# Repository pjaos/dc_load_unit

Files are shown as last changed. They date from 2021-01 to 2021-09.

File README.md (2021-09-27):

# DC Load Unit
I started this project with some basic requirements.

- Voltages up to 100 V
- Provide loads of up to 200W
- WiFi interface
- Web based interface providing stats and plotting capabilities

## Design
I used an ESP32 processor in the design as the main processor using  [Mongoose OS](https://mongoose-os.com/) After some investigations and prototyping I eventually settled on the schematic shown below.

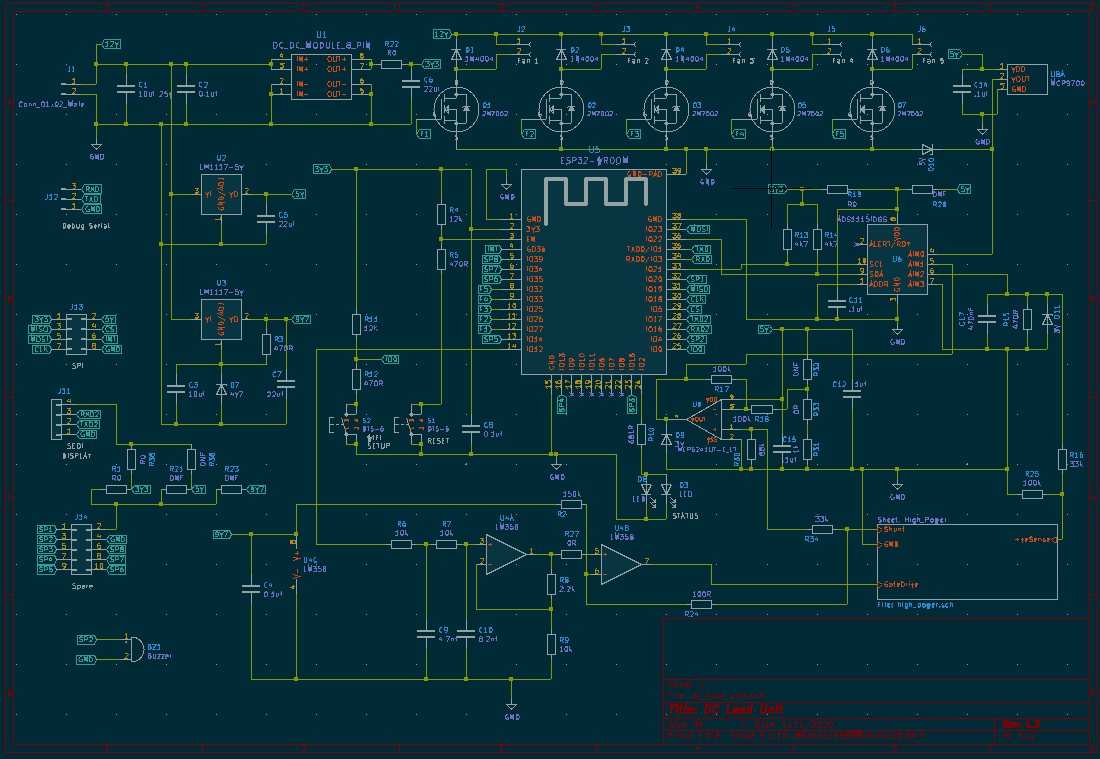
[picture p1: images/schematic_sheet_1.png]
Sheet 1

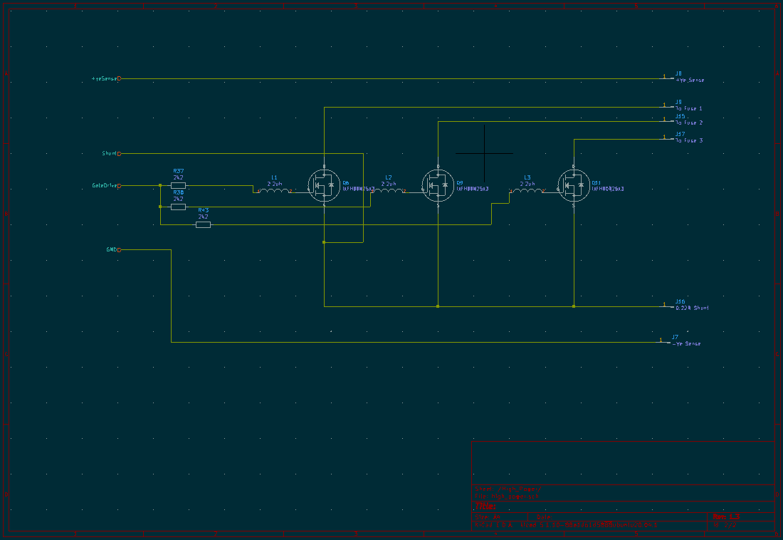
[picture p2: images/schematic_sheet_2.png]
Sheet 1


From the schematic a PCB was created as shown below

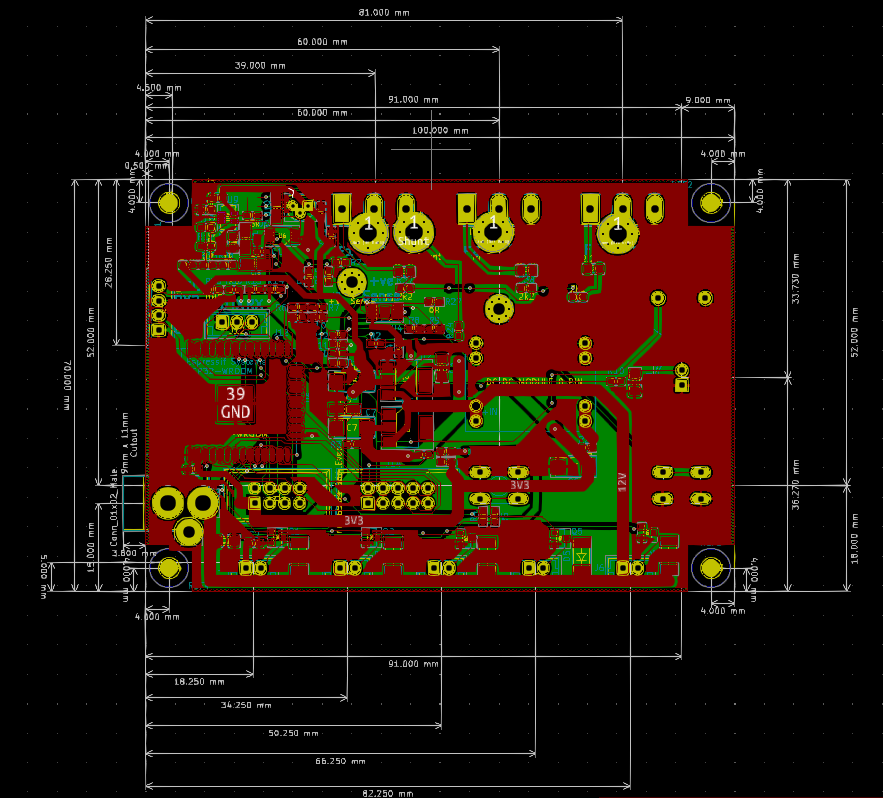
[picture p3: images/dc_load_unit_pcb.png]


Tests on completion of the load unit showed it was capable of providing a load of 280W.

- Images of the completed unit.

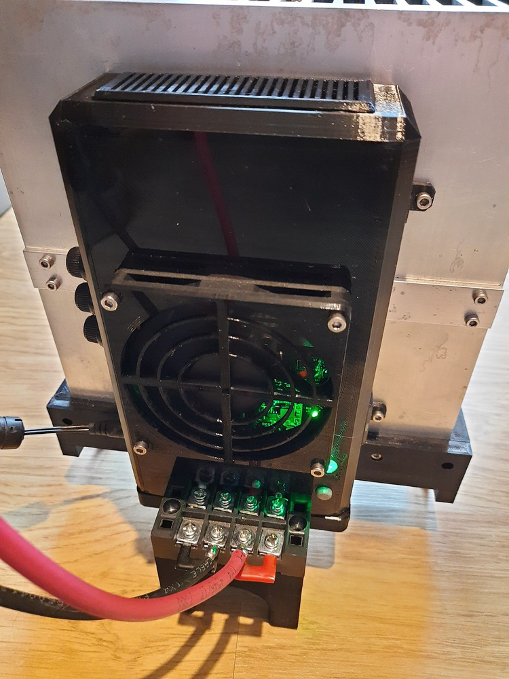
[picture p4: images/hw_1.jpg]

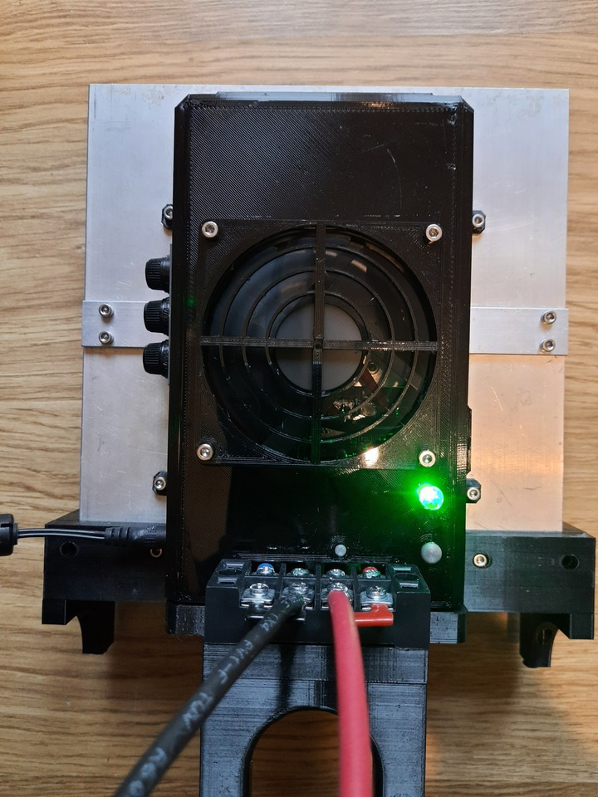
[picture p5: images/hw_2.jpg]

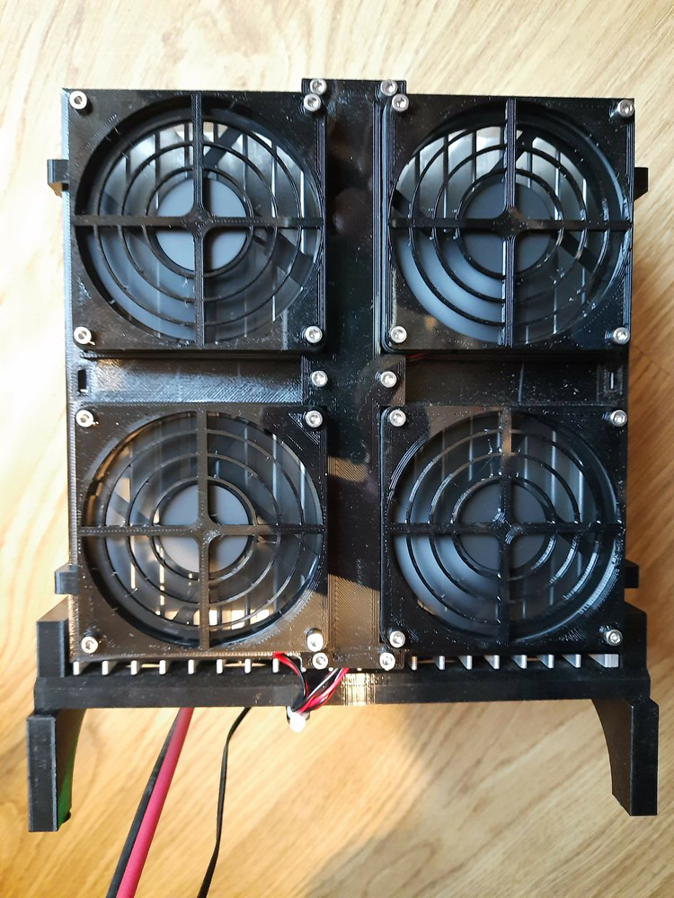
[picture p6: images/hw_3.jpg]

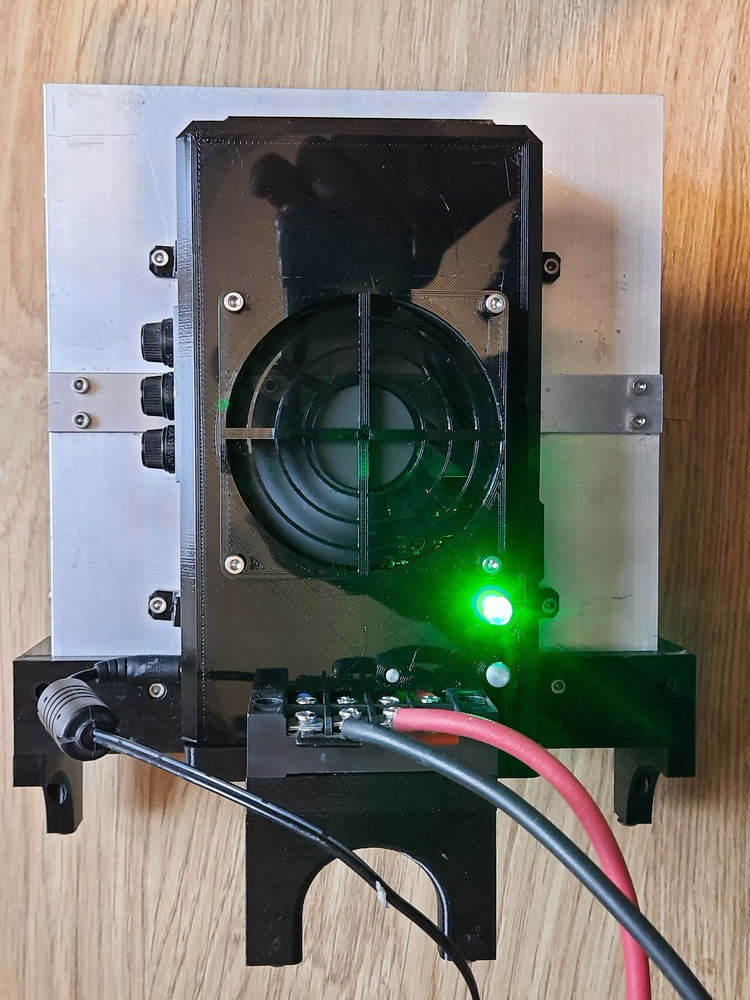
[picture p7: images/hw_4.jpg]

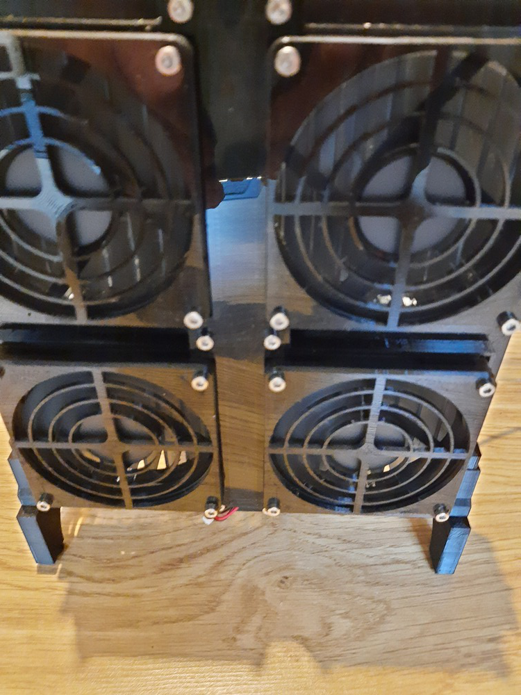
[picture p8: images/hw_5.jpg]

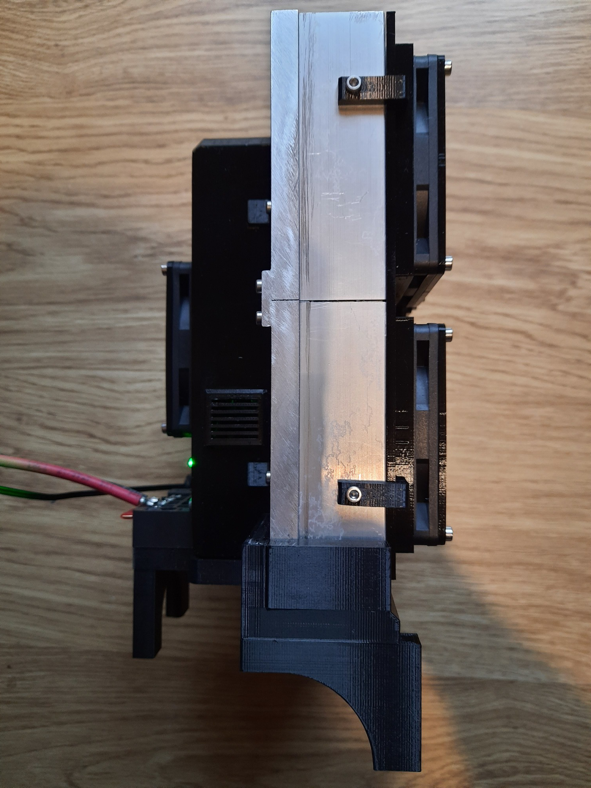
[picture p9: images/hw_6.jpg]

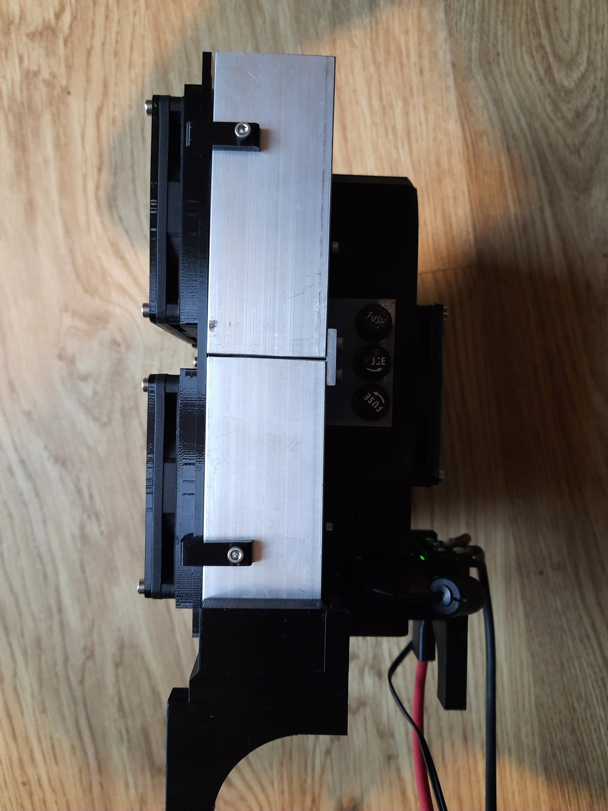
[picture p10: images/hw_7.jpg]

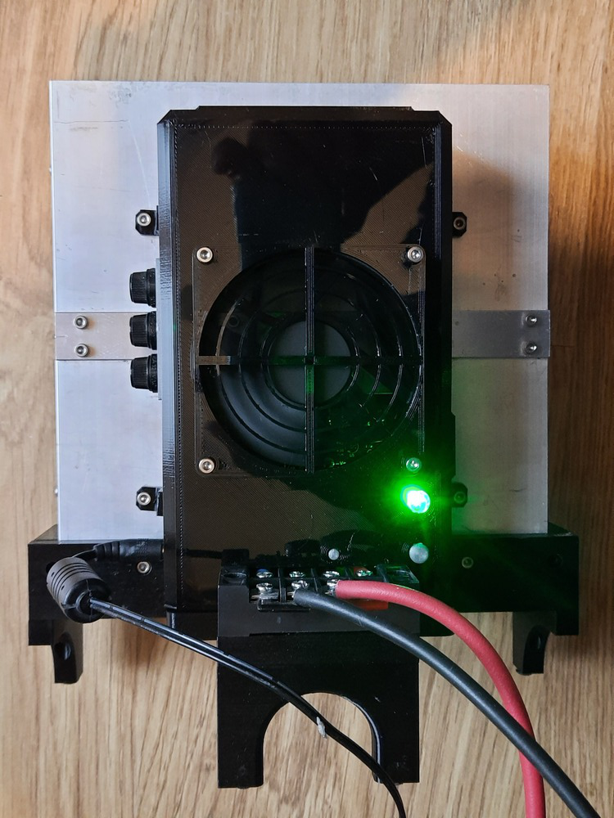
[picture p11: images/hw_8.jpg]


The green LED on the unit indicates that it is connected to the WiFi.

## Web interface
The web interface uses a tabbed pane structure as shown below.

### Main interface
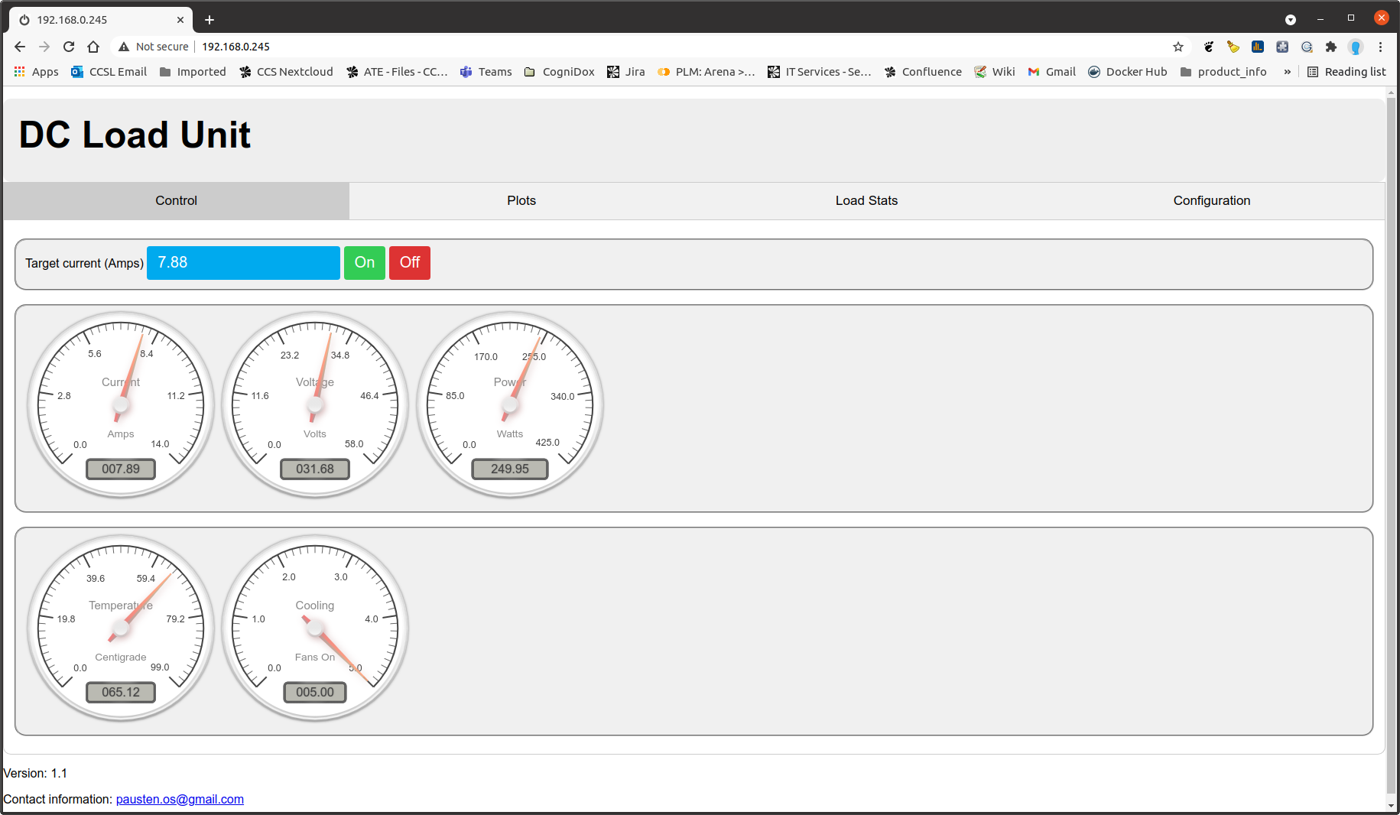
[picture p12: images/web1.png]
Initial Web page


- Plots
The plots tab displays the amps, volts, Watts and Temperature against time as show below.
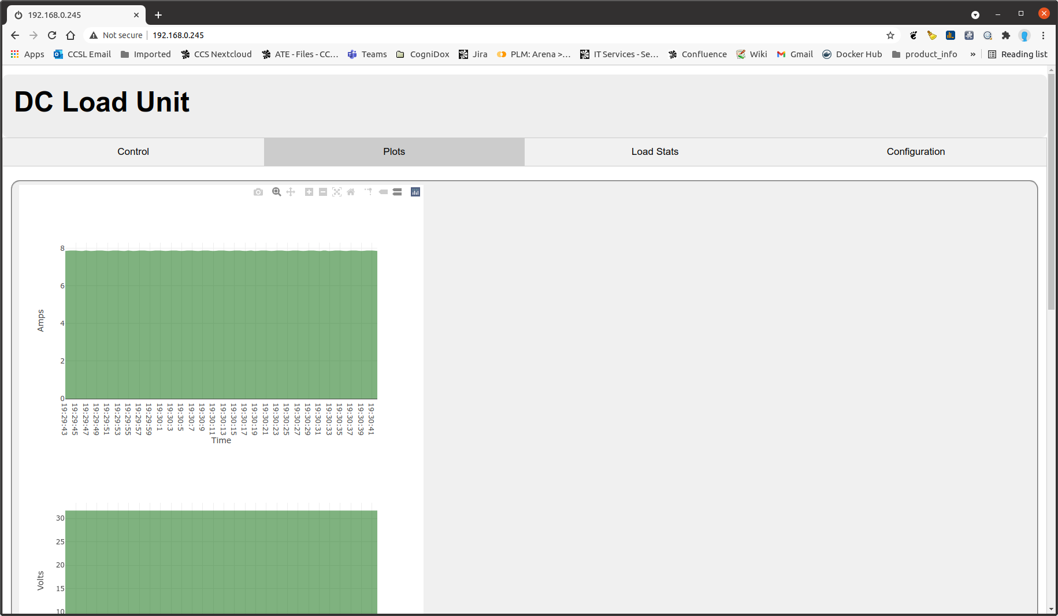
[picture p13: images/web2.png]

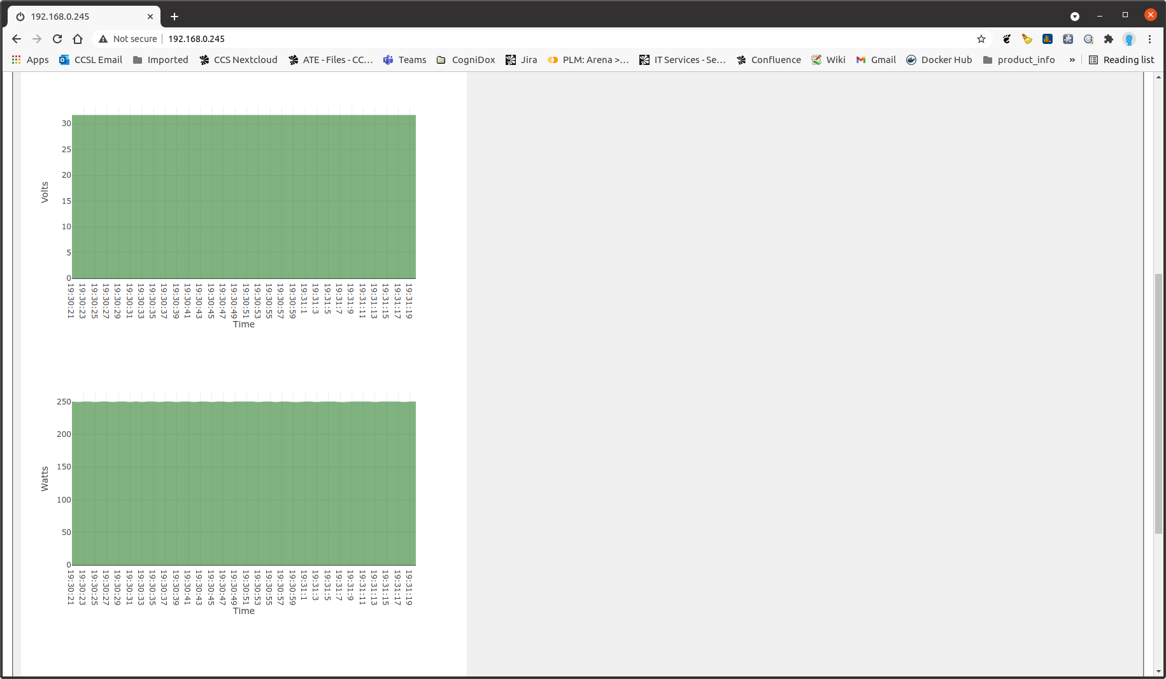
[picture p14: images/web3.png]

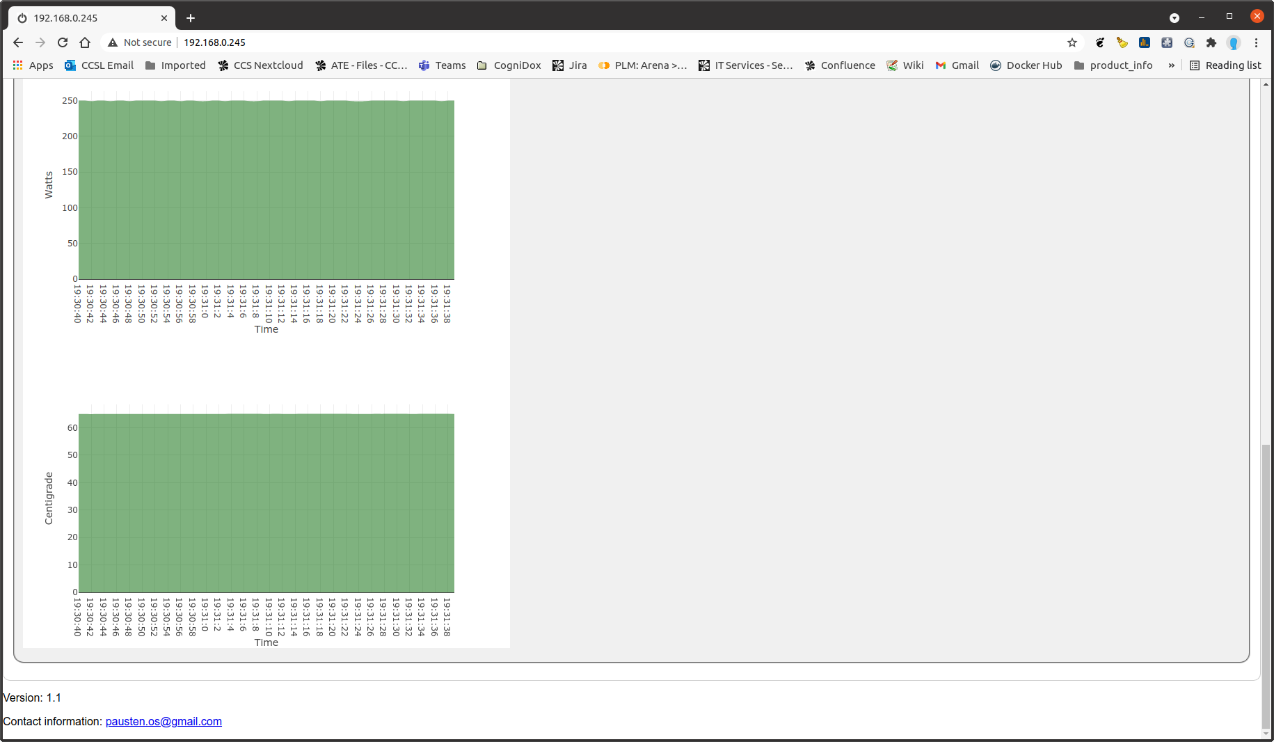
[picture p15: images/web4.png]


- Load stats
The load stats page records the load in amp hours and watt hours. The top two dials show the current accumulating values and the bottom two dials show the previous values. The previous values are useful for showing the total capacity of a battery tested.

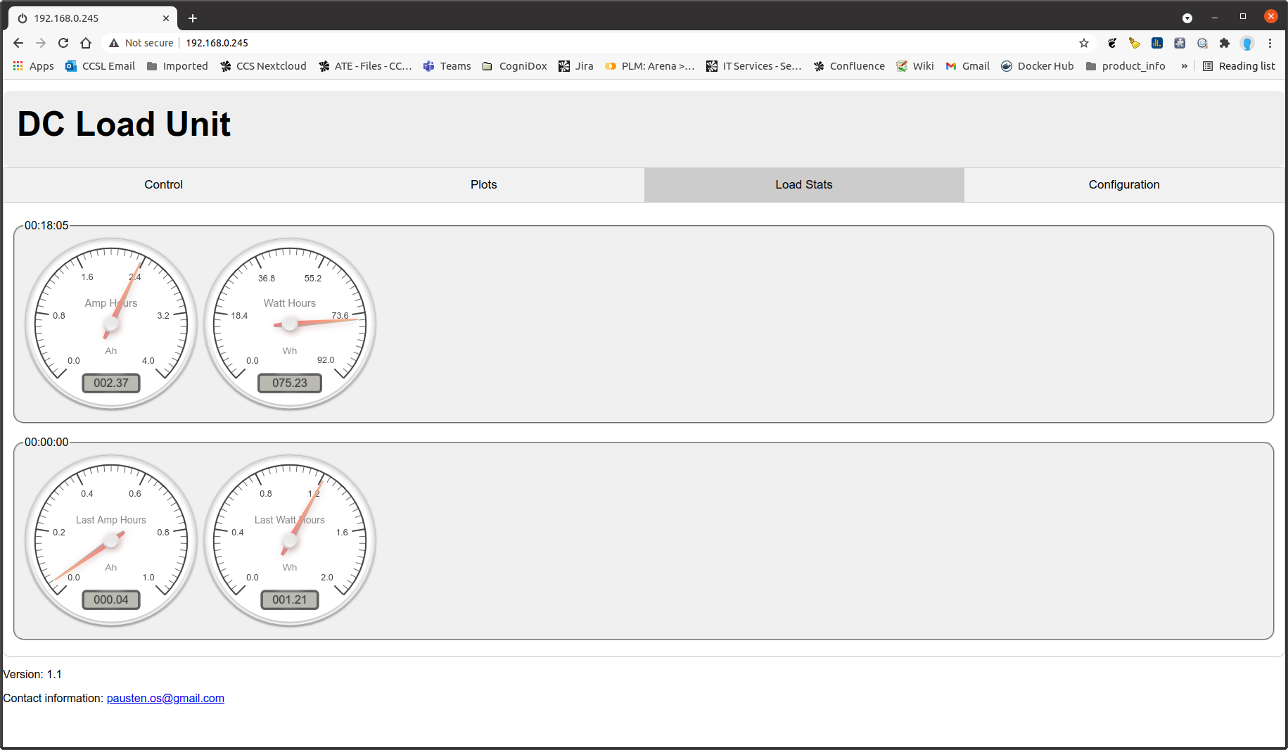
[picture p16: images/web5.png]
Load Stats


- Configuration
The configuration page details the settings for the unit as detailed below.

- Device name:

 The name that appears at the top of the web page and also in the [Yview](https://github.com/pjaos/yview) as the device provides integration into the YView network.

- Group name:

  The YView group name. See [Yview](https://github.com/pjaos/yview) for more details.

- Enable syslog

  If enabled then syslog data is sent to the source of the AYT messages (YView gateway).

- Max Plot values

  Defines the max number of points on the displayed plots.

- Max power

  This defines the maximum power the load will handle. This is limited to 280 Watts. When testing it can be useful to set this value to the max load that the device under test will deliver in order not to inadvertently overload the device under test.

- Load Shutdown Voltage

  When testing battery packs the voltage will drop as the battery looses charge. This setting allows the user to ensure the battery voltage does not drop to far possibly damaging the battery.

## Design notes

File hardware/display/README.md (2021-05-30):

# Display board
This was a side project of an LCD display board that could be used with the
dc load unit to control it. However the web interface is my preferred
GUI interface and therefore I did not develop this board any further.

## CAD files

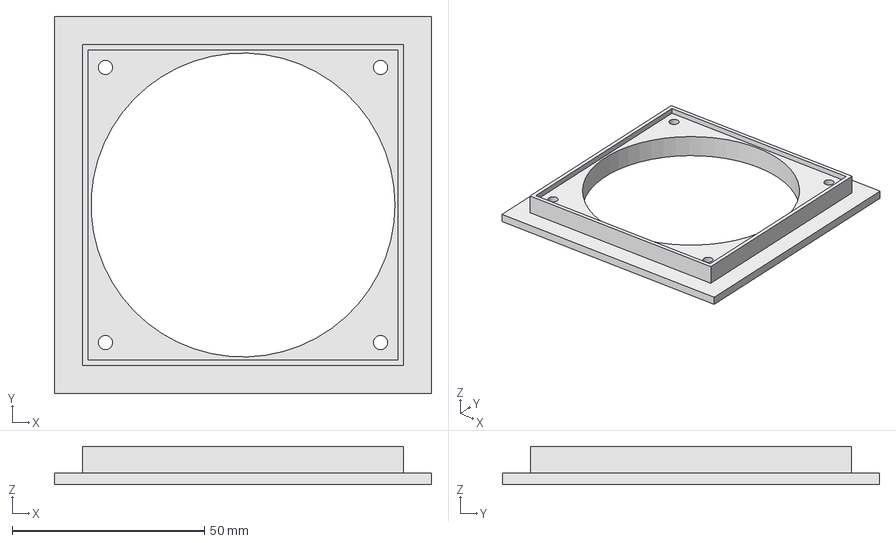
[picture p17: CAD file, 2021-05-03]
case/fan_test_part_1.FCStd
98.0 x 98.0 x 10.0 mm

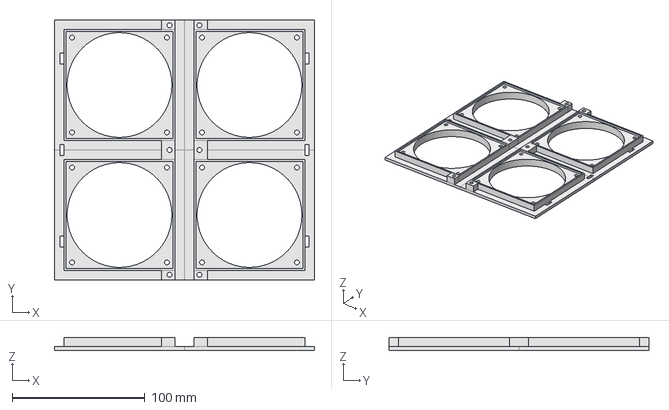
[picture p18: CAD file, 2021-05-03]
case/fan_holder_mk2.FCStd
196.0 x 196.0 x 10.0 mm

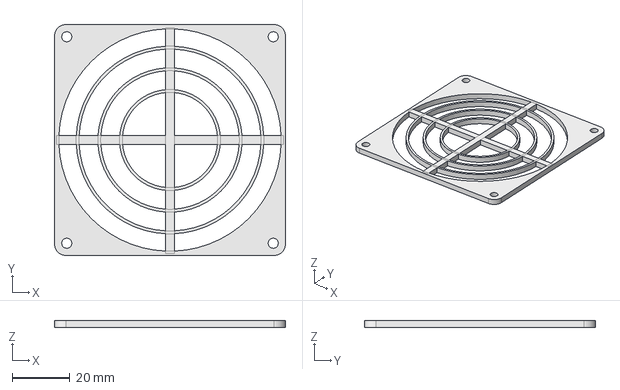
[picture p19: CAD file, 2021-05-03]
case/fan_cover_mk1.FCStd
80.0 x 80.0 x 2.50 mm

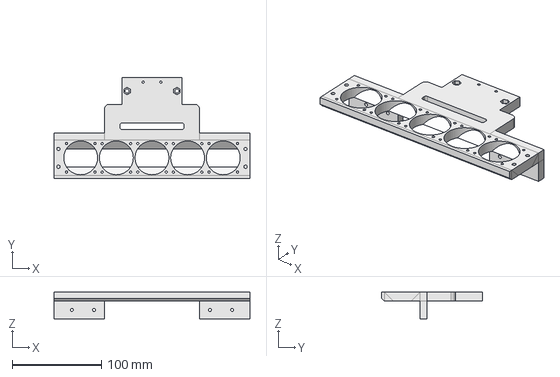
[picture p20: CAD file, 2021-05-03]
case/base_MK2.FCStd
220.0 x 113.0 x 30.0 mm

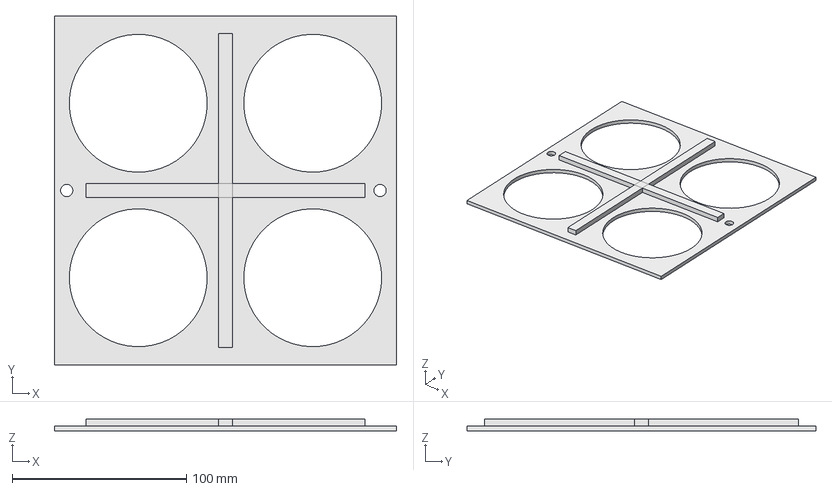
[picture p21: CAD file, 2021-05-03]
case/fan_holder_mk1.FCStd
196.0 x 200.0 x 7.00 mm

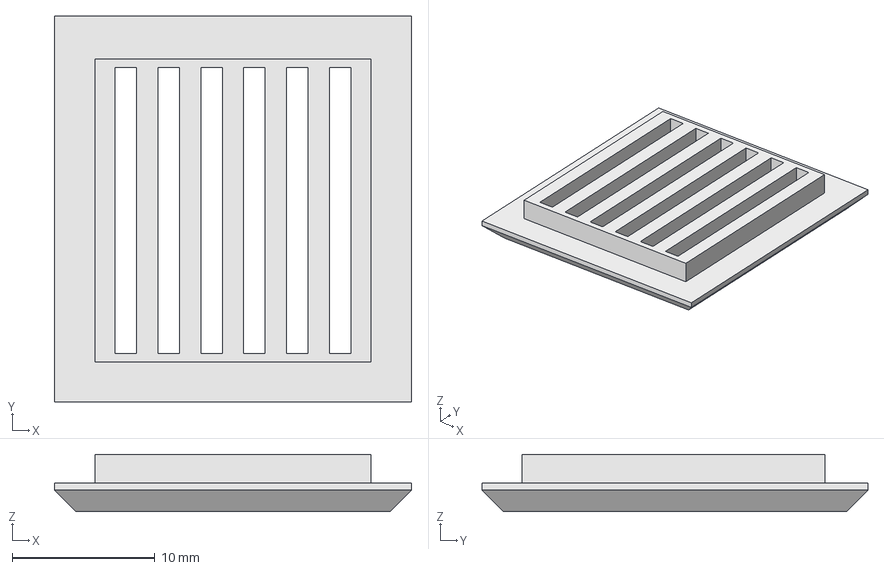
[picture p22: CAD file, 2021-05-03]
case/side_grill.FCStd
25.0 x 27.0 x 4.00 mm

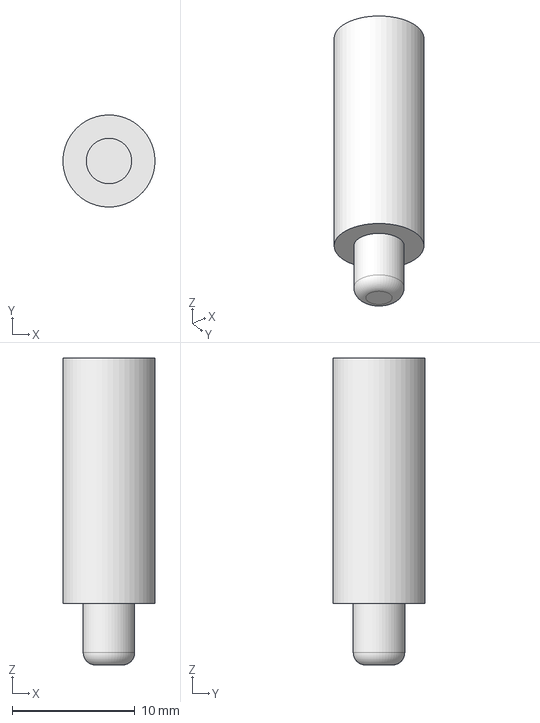
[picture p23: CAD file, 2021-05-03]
case/reset_button.FCStd
7.49 x 7.50 x 25.0 mm

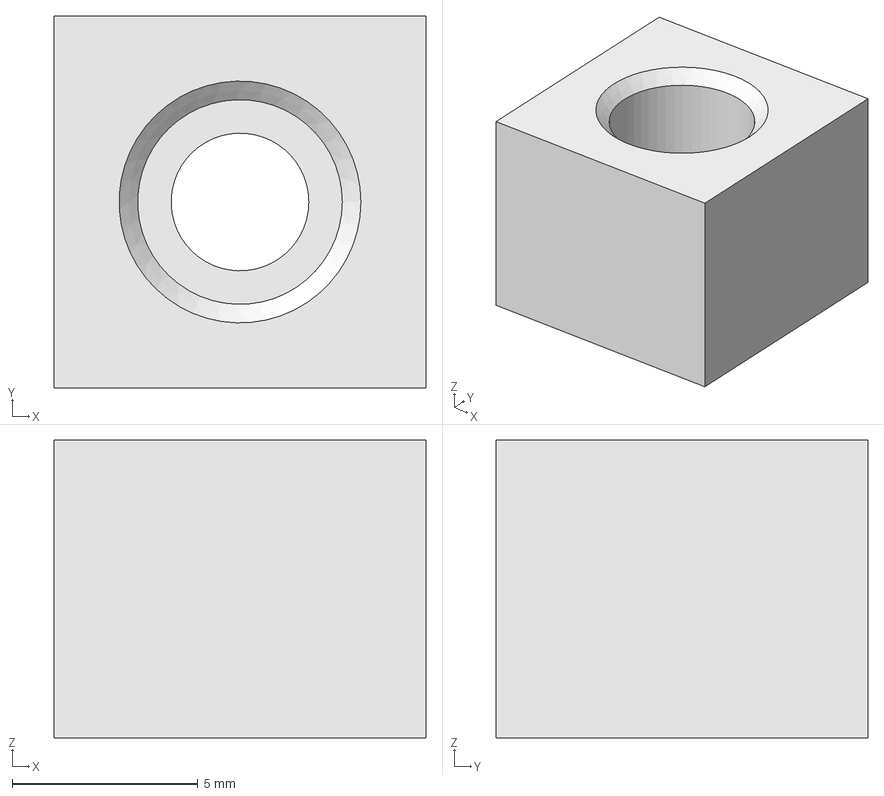
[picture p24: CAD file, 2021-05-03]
case/insert_test_part_mk1.FCStd
10.0 x 10.0 x 8.00 mm

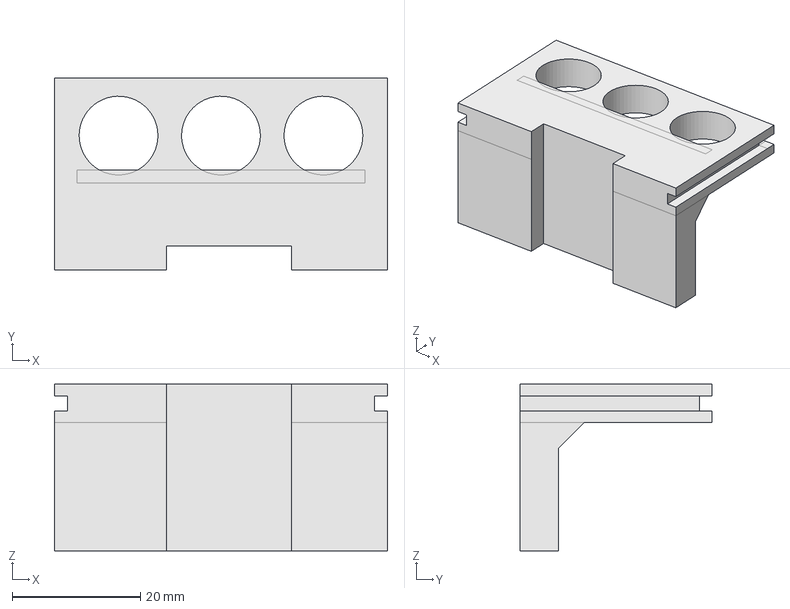
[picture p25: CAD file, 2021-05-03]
case/fuse_holder_bracket.FCStd
52.0 x 30.0 x 26.0 mm

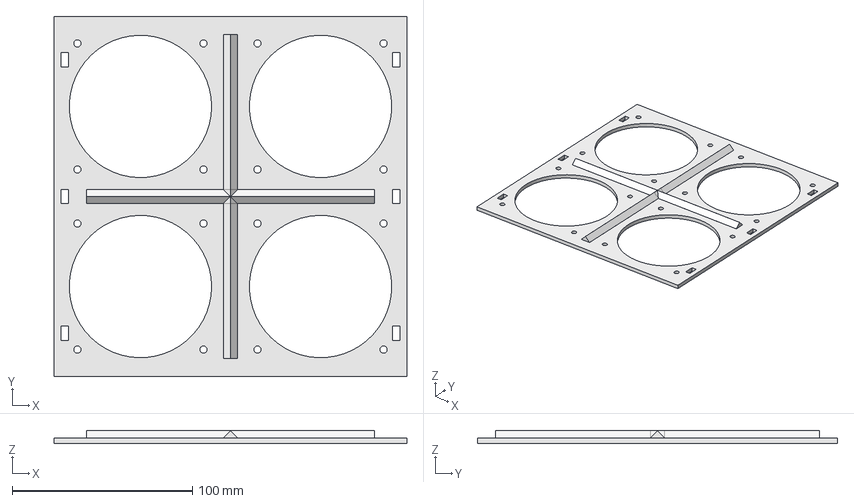
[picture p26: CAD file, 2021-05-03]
case/fan_holder.FCStd
196.0 x 200.0 x 7.00 mm

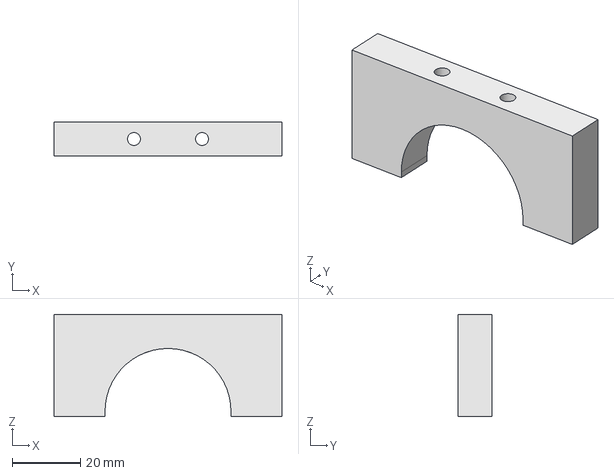
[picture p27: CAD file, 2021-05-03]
case/front_foot.FCStd
67.0 x 10.0 x 30.0 mm

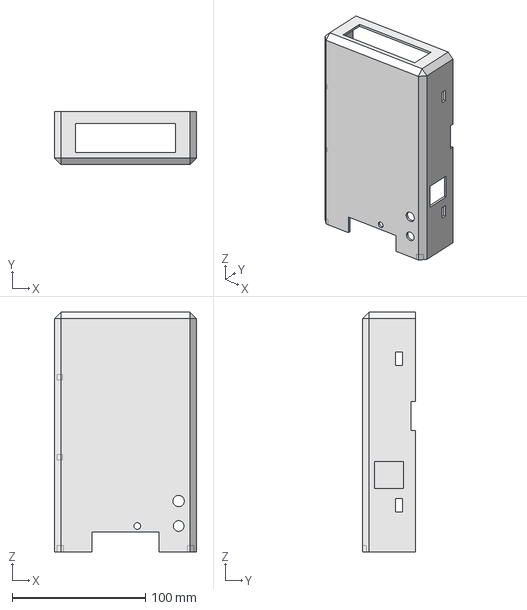
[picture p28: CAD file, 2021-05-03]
case/cover_mk2.FCStd
106.6 x 40.0 x 180.0 mm

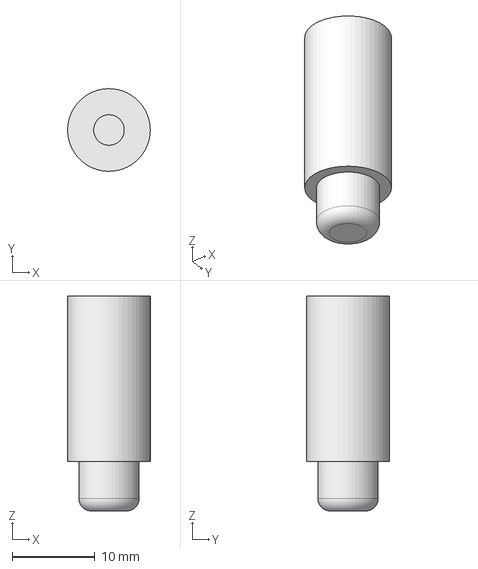
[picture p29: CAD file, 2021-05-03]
case/wifi_button.FCStd
9.99 x 10.00 x 26.0 mm

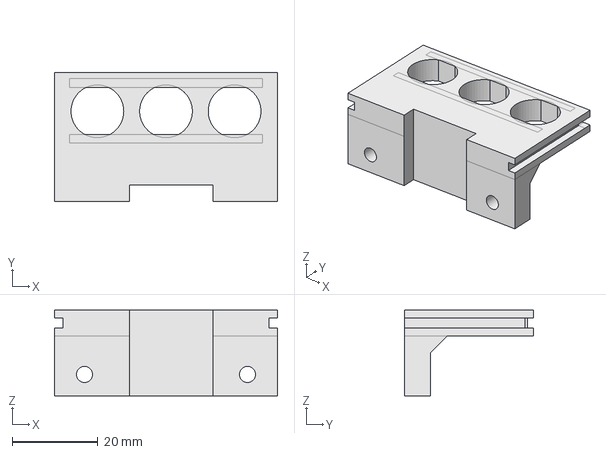
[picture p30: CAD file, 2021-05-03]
case/fuse_holder_bracket_mk1.FCStd
52.0 x 30.0 x 20.0 mm

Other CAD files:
case/fan_cover.FCStd
case/cover_mk3.FCStd
case/cover_mk1.FCStd
case/fan_holder_wire_cover.FCStd
case/base.FCStd
case/cover_bracket.FCStd
case/fan_cover_mk2.FCStd
case/fan_holder_clip_mk1.FCStd
case/front_foot_mk2.FCStd
case/insert_test_part_mk2.FCStd
case/pcb_washer.FCStd
case/rear_foot.FCStd
case/side_block.FCStd
case/spacer.FCStd
case/top_grill_mk1.FCStd

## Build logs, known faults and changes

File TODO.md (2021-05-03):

#TODO LIST

##Software
- Enable/Disable Javascript debugging messages.

##Hardware
- Hold reset and wifi buttons in causes load current to be drawn. This needs 
  investigation but is probably due to the reset state of ESP32 GPIO pins.

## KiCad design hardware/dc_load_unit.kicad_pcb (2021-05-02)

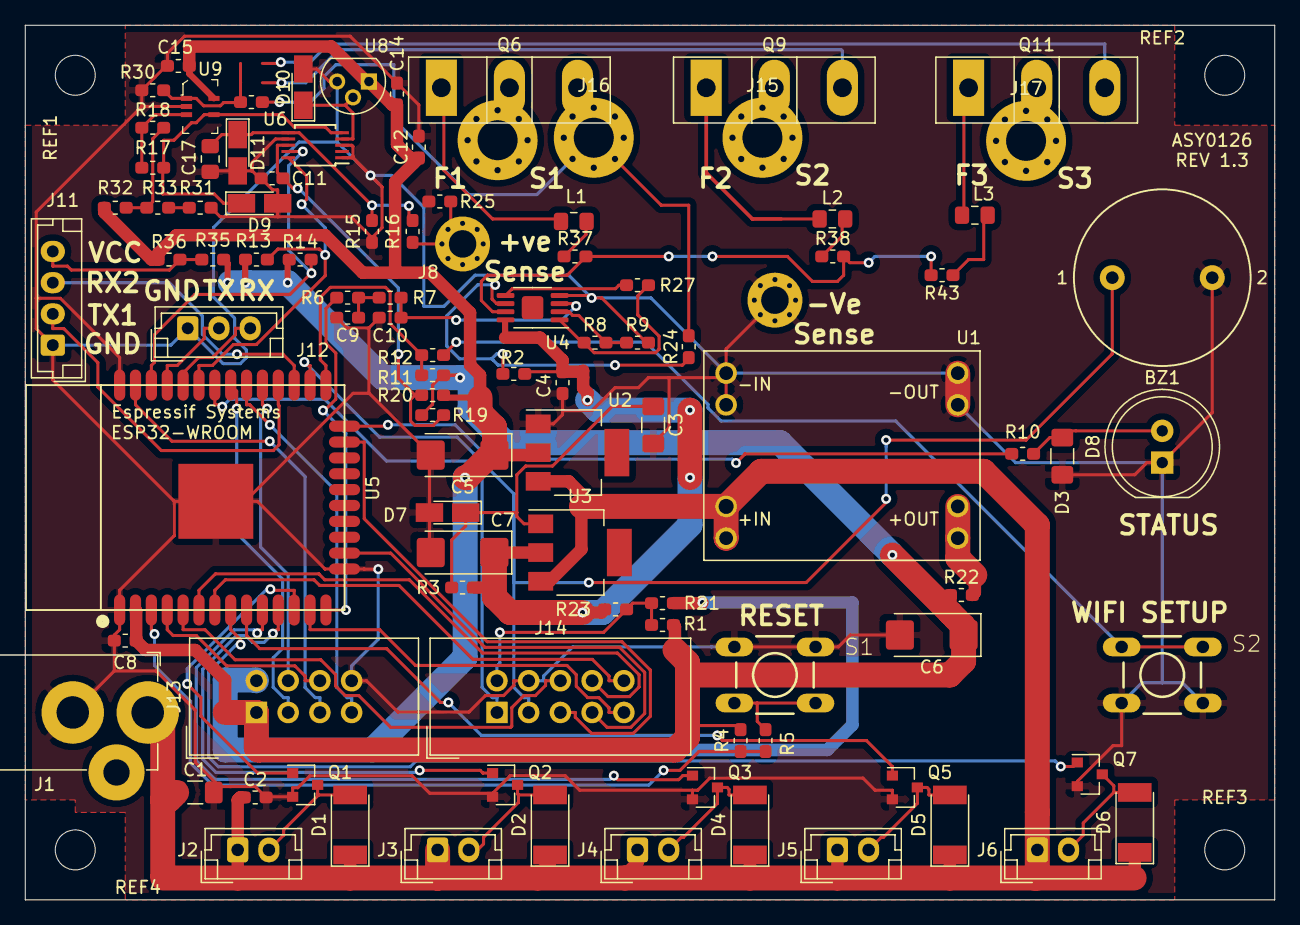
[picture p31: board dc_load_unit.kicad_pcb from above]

Board: 2 copper layers, 100.0 x 70.0 mm, 104 parts (0 on the bottom side), 71 nets.

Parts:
BZ1: Buzzer; Buzzer_14mm_8mm_pitch
C1: 10uf 25v; C_1206_3216Metric_Pad1.42x1.75mm_HandSolder
C2, C4, C8: 0.1uf; C_0603_1608Metric_Pad1.05x0.95mm_HandSolder
C3: 10uf; C_1206_3216Metric_Pad1.42x1.75mm_HandSolder
C5, C6, C7: 22uf; CP_EIA-6032-20_AVX-F_Pad2.25x2.35mm_HandSolder
C9: 4.7nf; C_0603_1608Metric_Pad1.05x0.95mm_HandSolder
C10: 8.2nf; C_0603_1608Metric_Pad1.05x0.95mm_HandSolder
C11, C12, C14, C15: .1uf; C_0603_1608Metric_Pad1.05x0.95mm_HandSolder
C17: 470nf; C_0805_2012Metric_Pad1.15x1.40mm_HandSolder
D1, D2, D4, D5, D6: 1N4004; D_MELF
D3: LED; C_1206_3216Metric_Pad1.42x1.75mm_HandSolder
D7: 4V7; D_MicroMELF_Hadsoldering
D8: LED; LED_D8.0mm
D9, D10, D11: 3V; D_MicroMELF_Hadsoldering
J1: Conn_01x02_Male; DC_power_2.1mm_5.5mm
J2, J3, J4, J5, J6: Conn_01x02_Female; JST_EH_B2B-EH-A_1x02_P2.50mm_Vertical
J7: -Ve Sense; MountingHole_2.2mm_M2_Pad_Via
J8: +Ve Sense; MountingHole_2.2mm_M2_Pad_Via
J9: To Fuse 1; MountingHole_3.2mm_M3_Pad_Via
J11: Conn_01x04; JST_EH_B4B-EH-A_1x04_P2.50mm_Vertical
J12: Conn_01x03_Male; JST_EH_B3B-EH-A_1x03_P2.50mm_Vertical
J13: Conn_02x04_Odd_Even; IDC-Header_2x04_P2.54mm_Vertical
J14: Conn_02x05_Odd_Even; IDC-Header_2x05_P2.54mm_Vertical
J15: To Fuse 2; MountingHole_3.2mm_M3_Pad_Via
J16: 0.22R Shunt; MountingHole_3.2mm_M3_Pad_Via
J17: To Fuse 3; MountingHole_3.2mm_M3_Pad_Via
L1, L2, L3: 2.2uh; L_0805_2012Metric_Pad1.15x1.40mm_HandSolder
Q1, Q2, Q3, Q5, Q7: 2N7002; SOT-23
Q6, Q9, Q11: IXFH80N25X3; TO-247-3_Vertical
R1, R19, R22, R35: R0; R_0603_1608Metric_Pad1.05x0.95mm_HandSolder
R2: 150k; R_0603_1608Metric_Pad1.05x0.95mm_HandSolder
R3, R5, R12, R15: 470R; R_0603_1608Metric_Pad1.05x0.95mm_HandSolder
R4: 12k; R_0603_1608Metric_Pad1.05x0.95mm_HandSolder
R6, R7, R9: 10k; R_0603_1608Metric_Pad1.05x0.95mm_HandSolder
R8: 2.2k; R_0603_1608Metric_Pad1.05x0.95mm_HandSolder
R10: 681R; R_0603_1608Metric_Pad1.05x0.95mm_HandSolder
R11: 12K; R_0603_1608Metric_Pad1.05x0.95mm_HandSolder
R13, R14: 4k7; R_0603_1608Metric_Pad1.05x0.95mm_HandSolder
R16, R34: 33k; R_0603_1608Metric_Pad1.05x0.95mm_HandSolder
R17, R18, R25: 100k; R_0603_1608Metric_Pad1.05x0.95mm_HandSolder
R20, R21, R23, R32, R36: DNF; R_0603_1608Metric_Pad1.05x0.95mm_HandSolder
R24: 100R; R_0603_1608Metric_Pad1.05x0.95mm_HandSolder
R27, R33: 0R; R_0603_1608Metric_Pad1.05x0.95mm_HandSolder
R30: 68k; R_0603_1608Metric_Pad1.05x0.95mm_HandSolder
R31: 1k; R_0603_1608Metric_Pad1.05x0.95mm_HandSolder
R37, R38, R43: 2k2; R_0603_1608Metric_Pad1.05x0.95mm_HandSolder
REF1, REF2, REF3, REF4: MountingHole_3.2mm_M3
S1, S2: DTS-6; switch-tact-DTS-6
U1: DC_DC_MODULE_8_PIN; mp1584_dc_dc
U2, U3: LM1117-5V; SOT-223
U4: LM358; MSOP-8-1EP_3x3mm_P0.65mm_EP1.73x1.85mm
U5: ESP32-WROOM
U6: ADS1115IDGS; TSSOP-10_3x3mm_P0.5mm
U8: MCP9700; TO-92
U9: MCP6241UT-E_LT; SC-70-5

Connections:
3V3: C6.1, C8.1, J13.1, R1.1, R4.1, R11.2, R13.1, R14.1, R19.2, R22.1, R35.1, U5.2
5V: C5.1, C12.1, C14.1, C15.1, J13.2, R20.1, R21.1, R32.2, R36.1, U2.2, U8.1, U9.5
9V7: C4.1, C7.1, R2.1, R3.2, R23.1, U3.2, U4.8
12V: C1.1, C2.1, D1.1, D2.1, D4.1, D5.1, D6.1, J1.1, J2.1, J3.1, J4.1, J5.1, J6.1, U1.3, U1.4, U2.3, U3.3
/High_Power/+veSense: J8.1, R16.2, R25.1
/High_Power/GateDrive: R37.2, R38.2, R43.2, U4.7
/High_Power/Shunt: J16.1, Q6.3, Q9.3, Q11.3, R24.2, R34.2
CLK: J13.7, U5.30
CS: J13.4, U5.29
F1: Q1.1, U5.12
F2: Q2.1, U5.11
F3: Q3.1, U5.10
F4: Q5.1, U5.9
F5: Q7.1, U5.8
GND: BZ1.2, C1.2, C2.2, C3.2, C4.2, C5.2, C6.2, C7.2, C8.2, C9.2, C10.2, C11.2, C12.2, C14.2, C15.2, C17.2, D3.1, D7.2, D8.1, D9.2, D10.2, D11.2, J1.2, J7.1, J11.1, J12.1, J13.8, J14.4, Q1.2, Q2.2, Q3.2, Q5.2, Q7.2, R9.2, R15.2, R25.2, R30.2, R31.1, S1.1, S1.2, S2.1, S2.2, U1.1, U1.2, U1.5, U1.6, U2.1, U4.4, U5.1, U5.15, U5.38, U5.39, U6.1, U6.3, U6.7, U8.3, U9.2
INT: J13.6, U5.4
IO0: R11.1, R12.2, U5.25
MISO: J13.3, U5.31
MOSI: J13.5, U5.37
unnamed: C3.1, D7.1, R3.1, U3.1
unnamed: C9.1, R6.1, R7.2
unnamed: C10.1, R7.1, U4.3
unnamed: C11.1, R19.1, R20.2, U6.8
unnamed: C17.1, D11.1, R15.1, R16.1, U6.6
unnamed: D1.2, J2.2, Q1.3
unnamed: D2.2, J3.2, Q2.3
unnamed: D3.2, D8.2, R10.1
unnamed: D4.2, J4.2, Q3.3
unnamed: D5.2, J5.2, Q5.3
unnamed: D6.2, J6.2, Q7.3
unnamed: D9.1, R17.1, U6.5, U9.4
unnamed: D10.1, U6.4, U8.2
unnamed: J9.1, Q6.2
unnamed: J11.4, R35.2, R36.2
unnamed: J14.2, R1.2, R21.2, R23.2
unnamed: J15.1, Q9.2
unnamed: J17.1, Q11.2
unnamed: L1.1, R37.1
unnamed: L1.2, Q6.1
unnamed: L2.1, R38.1
unnamed: L2.2, Q9.1
unnamed: L3.1, R43.1
unnamed: L3.2, Q11.1
unnamed: R2.2, R24.1, U4.6
unnamed: R4.2, R5.1, U5.3
unnamed: R5.2, S1.3, S1.4
unnamed: R6.2, U5.14
unnamed: R8.2, R9.1, U4.2
unnamed: R10.2, U5.24
unnamed: R12.1, S2.3, S2.4
unnamed: R13.2, U5.33, U6.10
unnamed: R14.2, U5.36, U6.9
unnamed: R17.2, R18.1, U9.3
unnamed: R18.2, R32.1, R33.2
unnamed: R22.2, U1.7, U1.8
unnamed: R27.1, U4.5
unnamed: R8.1, R27.2, U4.1
unnamed: R30.1, R34.1, U9.1
unnamed: R31.2, R33.1
RXD: J12.3, U5.34
RXD2: J11.3, U5.27
SP1: J14.1, U5.32
SP2: BZ1.1, J14.3, U5.26
SP3: J14.5, U5.23
SP4: J14.7, U5.16
SP5: J14.9, U5.13
SP6: J14.10, U5.7
SP7: J14.8, U5.6
SP8: J14.6, U5.5
TXD: J12.2, U5.35
TXD2: J11.2, U5.28

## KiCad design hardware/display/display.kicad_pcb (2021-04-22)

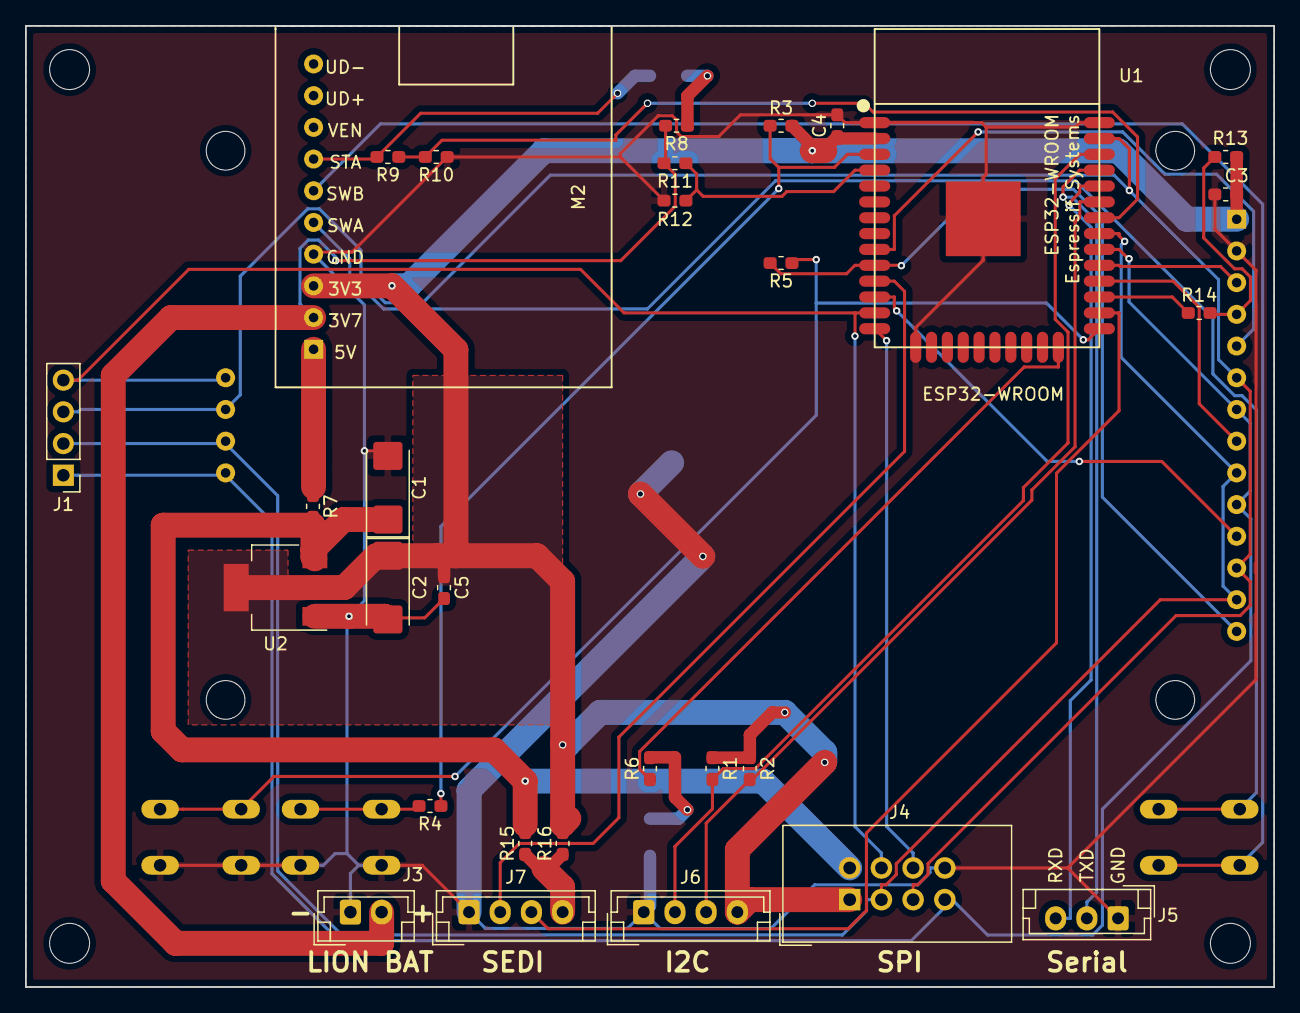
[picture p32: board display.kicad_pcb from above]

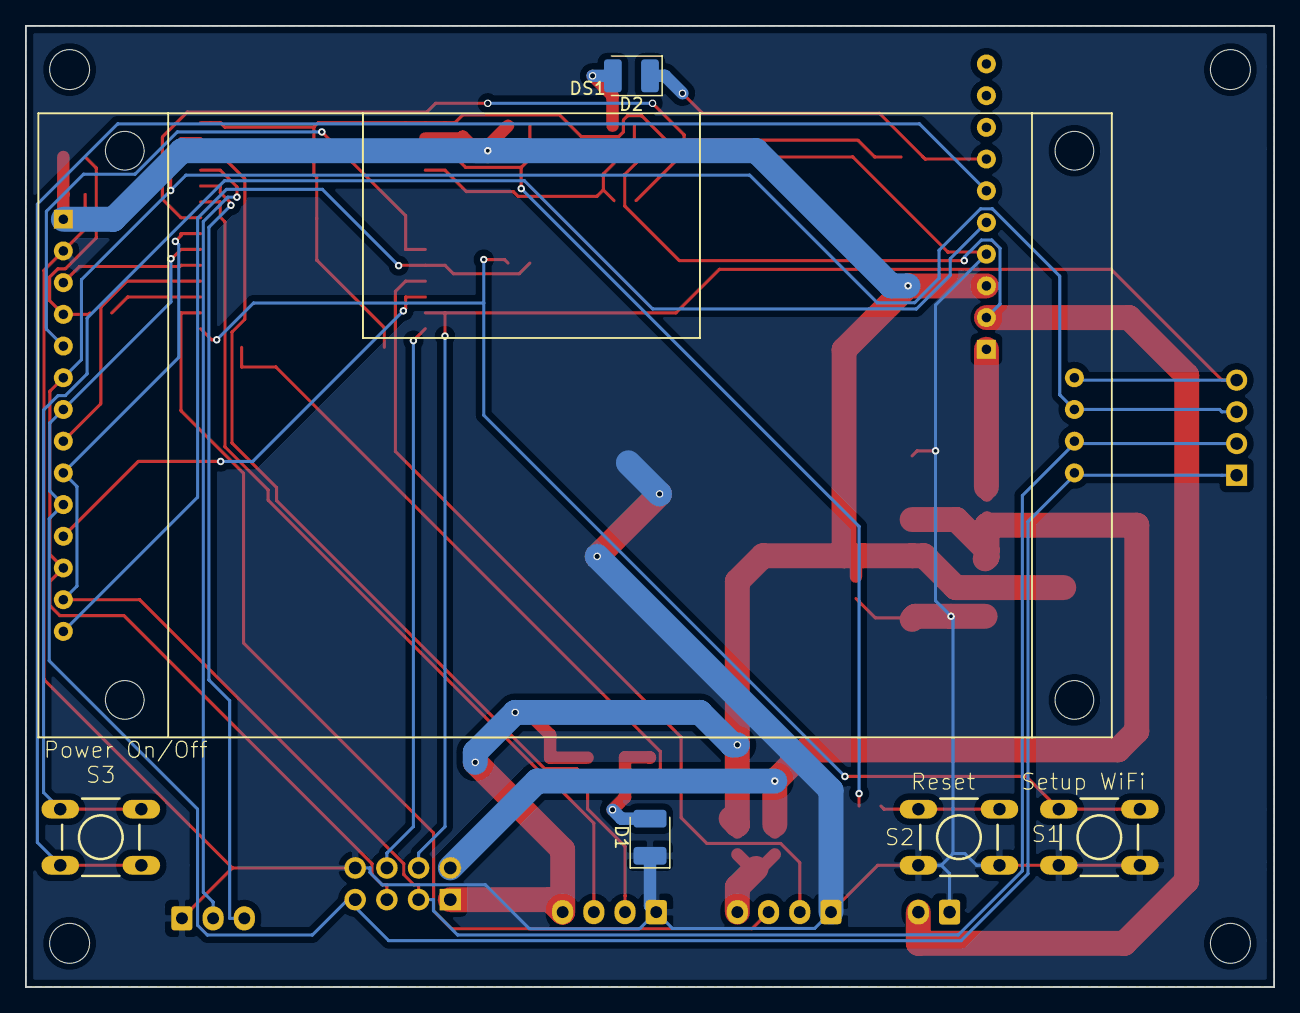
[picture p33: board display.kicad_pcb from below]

Board: 2 copper layers, 100.0 x 77.0 mm, 40 parts (6 on the bottom side), 35 nets.

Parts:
C1, C2: DNF; CP_EIA-6032-20_AVX-F_Pad2.25x2.35mm_HandSolder
C3, C4: 0.1uf; C_0603_1608Metric_Pad1.05x0.95mm_HandSolder
C5: DNF; C_0603_1608Metric_Pad1.05x0.95mm_HandSolder
D1, D2: LED; LED_1210_3225Metric_Pad1.42x2.65mm_HandSolder
DS1: display_2.8inch_ili9341; LCD_2.8_INCH_MSP2807
J1: Conn_01x04_Male; PinHeader_1x04_P2.54mm_Vertical
J3: Lion Bat; JST_EH_B2B-EH-A_1x02_P2.50mm_Vertical
J4: SPI; IDC-Header_2x04_P2.54mm_Vertical
J5: Serial; JST_EH_B3B-EH-A_1x03_P2.50mm_Vertical
J6: I2C; JST_EH_B4B-EH-A_1x04_P2.50mm_Vertical
J7: SEDI; JST_EH_B4B-EH-A_1x04_P2.50mm_Vertical
M2: usb_bat_pwr_module; USB_BAT_PWR_MODULE
MH1, MH2, MH3, MH4: MountingHole_3.2mm_M3
R1, R2: 1K; R_0603_1608Metric_Pad1.05x0.95mm_HandSolder
R3: 10K; R_0603_1608Metric_Pad1.05x0.95mm_HandSolder
R4, R6, R8: 470R; R_0603_1608Metric_Pad1.05x0.95mm_HandSolder
R5, R7: DNF; R_0603_1608Metric_Pad1.05x0.95mm_HandSolder
R9, R11: 68K; R_0603_1608Metric_Pad1.05x0.95mm_HandSolder
R10, R12: 100K; R_0603_1608Metric_Pad1.05x0.95mm_HandSolder
R13: 47K; R_0603_1608Metric_Pad1.05x0.95mm_HandSolder
R14, R15, R16: 0R; R_0603_1608Metric_Pad1.05x0.95mm_HandSolder
S1: Setup WiFi; switch-tact-DTS-6
S2: Reset; switch-tact-DTS-6
S3: Power On/Off; switch-tact-DTS-6
U1: ESP32-WROOM
U2: LM1117-3V3; SOT-223-3_TabPin2

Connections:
3V3: C2.1, C3.1, C4.1, C5.1, DS1.1, J4.1, J6.4, M2.3, R1.1, R2.1, R3.2, R13.1, R16.2, U1.2, U2.2
5V: C1.1, J4.2, R7.2, R15.2, U2.3
/5VBAT: M2.1, R7.1
/BAT+: J3.2, M2.2, R8.2, R11.2
CS0: DS1.3, U1.29
CS1: DS1.11, U1.12
CS2: DS1.15, J1.4, J4.4, U1.13
DRX: J7.3, U1.26
DTX: J7.2, U1.11
GND: C1.2, C2.2, C3.2, C4.2, C5.2, D1.1, DS1.2, J3.1, J4.8, J5.1, J6.1, J7.1, M2.4, R10.1, R12.1, S1.1, S1.2, S2.1, S2.2, U1.1, U1.15, U1.38, U1.39, U2.1
INT: J4.6, U1.14
MISO: DS1.9, DS1.13, DS1.17, J1.2, J4.3, U1.31
MOSI: DS1.6, DS1.12, DS1.16, J1.3, J4.5, U1.37
unnamed: D1.2, R6.2
unnamed: D2.1, M2.7, R9.2
unnamed: D2.2, R8.1
unnamed: DS1.4, R13.2, R14.2
unnamed: DS1.5, U1.9
unnamed: DS1.8, U1.28
unnamed: DS1.14, R5.2, U1.10
unnamed: J7.4, R15.1, R16.1
unnamed: M2.5, S3.3, S3.4
unnamed: M2.6, S3.1, S3.2
unnamed: R3.1, R4.1, U1.3
unnamed: R4.2, S2.3, S2.4
unnamed: R5.1, S1.3, S1.4, U1.25
unnamed: R6.1, U1.24
unnamed: R9.1, R10.2, U1.32
unnamed: R11.1, R12.2, U1.4
unnamed: R14.1, U1.27
RXD: J5.3, U1.34
SCK: DS1.7, DS1.10, DS1.18, J1.1, J4.7, U1.30
SCL: J6.3, R2.2, U1.33
SDA: J6.2, R1.2, U1.36
TXD: J5.2, U1.35

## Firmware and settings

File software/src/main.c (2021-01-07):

#include <mgos.h>
#include <ydev_ayt_handler.h>

#include "ayt_tx_handler.h"
#include "rpc_handler.h"
#include "timer.h"
#include "fan.h"

/**
 * @brief The MGOS program entry point.
 **/
enum mgos_app_init_result mgos_app_init(void) {
  //Init, no load
  set_load(0.0);

  //Turn all fans off
  init_fans();

  rpc_init();

  add_ayt_response_handler(send_ayt_response);

  init_timers();

  return MGOS_APP_INIT_SUCCESS;
}

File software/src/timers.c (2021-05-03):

#include <mgos.h>
#include <mgos_i2c.h>
#include <mgos_pwm.h>
#include <ads111x.h>
#include <mgos_syslog.h>
#include <mgos_system.h>
#include <math.h>

#include "mgos_time.h"
#include "timer.h"
#include "fan.h"
#include "log.h"

#define ADS111X_I2C_ADDRESS 72
#define PWM_PIN             12
#define PWM_FREQ            78000
//#define VOLTAGE_CNV_FACTOR  225.38
#define VOLTAGE_CNV_FACTOR  140.25
#define MCP9700_CODES_PER_VOLT 16022.0
#define MCP9700_VOUT_0C        0.5
#define MCP9700_TC             0.01

#define CORRECTION_FACTOR 0.91621
#define CODES_PER_AMP 2878.0

#define NO_AMPS_MV 18.7
#define ADC_READING_COUNT 3

#define MEM_USAGE_TIMER_PERIOD_MS 1000
#define POLL_TEMP_TIMER_PERIOD_MS 1000
#define PID_LOOP_TIMER_PERIOD_MS 250

#define OFF_LOAD_FACTOR 0.15 //The PWM value at which the load is off
#define OFF_VOLTAGE 0.05     //If the voltage is lower than this the load is considered off

#define DEFAULT_PROPORTIONAL_COEFF 0.08
#define DEFAULT_INTEGRAL_COEFF 0.04
#define DEFAULT_DERIVATIVE_COEFF 0.000

#define MAX_VOLTAGE 100 //The max voltage that should be applied to the load.
#define MAX_AMPS 10.0

#define MIN_LOAD_CURRENT 0.01 //The minimum setable load current.
#define INITIAL_LOAD_PWM 0.25

#define BUZZER_GPIO 4 // The GPIO pin that the buzzer is connected to.
#define WARNING_TONE_PERIOD_MS 500

//If enabled this reports the memory usage on the serial output and via syslog
//#define REPORT_MEM_USAGE 1

//If enabled this sets the unit to a mode where the REST pwm call must be used to set the PWM load output directly.
//#define PWM_DEBUG 1

//If enabled this reports the temp device reads on the serial output and via syslog
//#define SHOW_TEMP_DEBUG 1

//If enabled this reports the load input voltage debug on the serial port and via syslog
//#define DEBUG_VOLTAGE_READ 1

//If enabled this reports pid loop debug info on the serial port and via syslog
#define PID_LOOP_DEBUG 1

//If enabled this reports attempts to set the load (from user) on the serial port and via syslog
#define SET_LOAD_DEBUG 1

static bool warningToneOn = false; //If true then the buzzer will emit a tone
static bool warningToneHigh = false; //If the warning tone is on and this is true then a high warning tone will be heard.
                                     //If the warning tone is on and this is false then a low warning tone will be heard.

static float kP = DEFAULT_PROPORTIONAL_COEFF;
static float kI = DEFAULT_INTEGRAL_COEFF;
static float kD = DEFAULT_DERIVATIVE_COEFF;

extern char syslog_msg_buf[SYSLOG_MSG_BUF_SIZE];

float target_amps                   = 0.0;
bool  target_amps_changed           = false;
float max_watts                     = 0.0;
bool  temp_alarm                    = false;
float temp_now                      = 0.0;
float amps_now                      = 0.0;
float volts_now                     = 0.0;
float watts_now                     = 0.0;
float pwmValue                      = 0.0;
float maxPWMValue                   = 1.0;

float min_load_voltage              = 0.0;
bool  min_load_voltage_alarm        = false;
bool  load_on                       = false;
bool  last_load_on_state            = false;
bool  max_watts_alarm               = true;
int64_t start_load_on_time_usecs    = 0.0; //The time at which the load was last switched on
int64_t stop_load_on_time_usecs     = 0.0; //The time at which the load was switched off
int64_t last_pid_loop_us            = 0;
float ampSeconds                    = 0.0;
float amp_microseconds              = 0.0;
float watt_microseconds             = 0.0;
float previous_amp_microseconds     = 0.0;
float previous_watt_microseconds    = 0.0;
bool  max_load_voltage_alarm        = false;

#define PWM_TABLE_SIZE 19
//Lookup table for relationship between amps and PWM value
//First column is amps, second column is PWM value
//These values were arrived at testing by setting the PWM value and measuring the current.
static float pwm_lut[PWM_TABLE_SIZE][2] = {
        {0.016, 0.002},
        {0.042, 0.003},
        {0.068, 0.004},
        {0.095, 0.005},
        {0.122, 0.006},
        {0.148, 0.007},
        {0.174, 0.008},
        {0.201, 0.009},
        {0.227, 0.010},
        {0.49,  0.020},
        {0.905, 0.035},
        {2.022, 0.077},
        {3.63,  0.141},
        {5.01,  0.201},
        {6.0,   0.247},
        {6.8,   0.292},
        {7.7,   0.341},
        {8.5,   0.39},
        {9.6,   0.457},
};

/**
 * @brief Get the load resistance index.
 * @param amps The required load current in amps.
 * @param high If 1 then take the value above >= the a in the pwm_lut table, else take the <= the pwm_lut in the table.
 * @return The pwm table index.
 */
static int get_amps_index(float amps, int high) {
    int index=0, s_index=0;

    if( high ) {
        //Search from bottom up to find first value >= amps
        for( index=0 ; index <PWM_TABLE_SIZE ; index++ ) {
            if ( pwm_lut[index][0] >= amps ) {
                s_index = index;
                break;
            }
        }
    }
    else  {
        //Search from top down to find first value <= amps
        for( index=PWM_TABLE_SIZE-1 ; index >= 0 ; index-- ) {
            if( pwm_lut[index][0] <= amps ) {
                s_index = index;
                break;
            }
        }
    }

    return s_index;
}

/**
 * @brief Determine the PWM value to give the required load current.
 *        This uses the pwm look up table and performs linear interpolation to determine the PWM value.
 * @param amps The required load current in amps.
 * @return the pwm value to set.
 */
static float get_pwm_value(float amps) {
    float x0,y0,x1,y1;
    int low_index = get_amps_index(amps, 0);
    int high_index = get_amps_index(amps, 1);

    //If we have the exact value
    if( low_index == high_index ) {
        return pwm_lut[low_index][1];
    }
    x0= pwm_lut[low_index][0];
    y0= pwm_lut[low_index][1];

    x1= pwm_lut[high_index][0];
    y1= pwm_lut[high_index][1];

    return y0 + ((y1-y0)/(x1-x0)) * (amps - x0);
}

/**
 * @brief Callback to send periodic updates of the memory and file system state.
 **/
static void mem_usage_cb(void *arg) {

    size_t heap_zize          = mgos_get_heap_size();
    size_t free_heap_size     = mgos_get_free_heap_size();
    size_t min_free_heap_size = mgos_get_min_free_heap_size();
    size_t fs_size            = mgos_get_fs_size();
    size_t fs_free_size       = mgos_get_free_fs_size();
    snprintf(syslog_msg_buf, SYSLOG_MSG_BUF_SIZE, "uptime=%.2lf, heap=%d, heap_free=%d heap_min=%d, total_disk_space=%d, free_disk_space=%d",  mgos_uptime(), heap_zize, free_heap_size, min_free_heap_size, fs_size, fs_free_size);
    log_msg(LL_INFO, syslog_msg_buf);
    (void) arg;
}

/**
 * @brief Turn the load off.
 * @return
 */
static void set_load_off() {
    set_load(0.0);
    snprintf(syslog_msg_buf, SYSLOG_MSG_BUF_SIZE, "Turned load off");
    log_msg(LL_INFO, syslog_msg_buf);
}
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

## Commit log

2021-01-07 Initial commit of the dc load hardware and software.
    [dc_load_unit-B_Cu.gbr, dc_load_unit-B_Mask.gbr, dc_load_unit-B_SilkS.gbr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]
2021-01-09 - Add log level to the log_msg function. - Add RPC to reset temp alarms - Add RPC to set debug level. Sys.SetDebug exists but takes three arguments.
    [fan.c, rpc_handler.c, timers.c]
2021-01-20 - Added 2.2 uh inductors to MOSFET gates to stop parasitic OSC - Added 470nf cap accross R15.
    [dc_load_unit.sch]
2021-01-20 Changed Watts text to Power.
2021-01-20 Make fan API simpler.
2021-01-20 Use new fan API and improve the load off definition.
2021-01-26 - initial implementation of PID load control. - Add fan count dial to monitor cooling.
2021-01-26 Change web interface current input field label from 'Current (Amps)' to 'Target Current (Amps)'
2021-01-26 Add rpcs for calibrating amps and volts.
2021-01-26 - Set the default voltage and current calibration values. - Constantly adjust the amps rather than settling in a band.
2021-01-26 - Fixed bug in fan status in web interface. Dial shows off fan still running as temperature is dropping.
    [fan.c]
2021-01-27 Add load off button that resets the load to 0.
2021-01-31 Add rpc handler to reboot the unit.
    [rpc_handler.c]
2021-01-31 Add RPC to set the min load voltage. When the load voltage drops to this level the load turns off.
2021-02-01 Add load shutdown voltage options. When the voltage reaches this voltage the load automatically turns off. Useful when testing batteries.
2021-02-02 Limit the minimum voltage so that the voltage dial does not move around below 30 MV.
2021-02-03 Report a temp alarm to the user. When the temp of the heatsink reaches a maximuum (79C) the load is shutdown and this is reported to the user via a dialog box which blocks access to the GUI until the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
2021-02-06 Reinstate tablinks class as it's used un the Javascript to select the current tab.
2021-02-06 Add a min low voltage alarm that is reported in the web browser as a dialog that appears. When the user clicks the OK button in the dialog the alarm is reset. This is only reported if the load is on.
    [rpc_handler.c, timers.c]
2021-02-06 R16 changed from 47k to 33k to get better resolution on the ADC.
    [dc_load_unit.sch]
2021-02-06 - If a voltage of 200V is detected on the DC load terminal the load is shiut down. - Add a MAX load voltage warning to the web GUI.
2021-02-06 If a voltage of 200V is detected on the DC load terminal the load is shiut down.
2021-03-06 Update schematic and PCB to use shunt resistors to measure throughtput and add FET protection for over current.
    [dc_load_unit-B_Cu.gbr, dc_load_unit-B_Mask.gbr, dc_load_unit-B_SilkS.gbr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]
2021-03-06 Add support for warning buzzer on dc load unit.
    [rpc_handler.c, timers.c]
2021-04-22 C1 changed from DNF to 10uf C2 changed from DNF to 22uf R16 changed form 0R to DNF
    [display.kicad_pcb, display.sch]
2021-04-22 R10 330R -> 681R as LED is too bright R25 3.3k -> 2.2k to change low end gate voltage
    [dc_load_unit.kicad_pcb, dc_load_unit.sch]
2021-05-02 Rev 1.3 single shunt with op amp drive change to make gate drive voltage directly related to load current.
    [dc_load_unit-B_Cu.gbr, dc_load_unit-B_Mask.gbr, dc_load_unit-B_SilkS.gbr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]
2021-05-02 Add jbcl rev 1.3 gerber package.
2021-05-02 Add high power schematic sheet.
    [high_power.sch]
2021-05-03 Add document to detail how to call the REST interface methods on the dc load unit.
    [base.FCStd, base_MK2.FCStd, cover_bracket.FCStd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]
2021-05-03 Add ability to set a limit on the max power the load will handle. This triggers a warning if the user enters a current value that breaks this limit.
2021-05-03 Correct #define to #ifdef
    [timers.c]
2021-05-03 Limit the MAX power of the DC load to 280 Watts.
2021-09-27 Add details of the PCB.
2024-03-03 Add a 10uf 250v capacitor to the input sense lead to ensure we don't get over voltage errors when the sense lead is touched by human hand.
    [dc_load_unit.sch]
